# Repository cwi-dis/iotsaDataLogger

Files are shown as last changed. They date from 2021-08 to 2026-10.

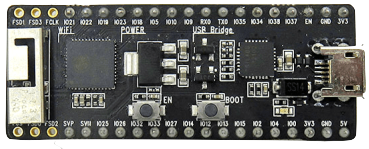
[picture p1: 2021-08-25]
extras/hardware/esp32-pico-kit-dev-board-v4-01.png

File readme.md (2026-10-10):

# iotsaDataLogger - web server to record time series from a sensor




IotsaDataLogger reads an analog sensor repeatedly at a configurable interval and records readings in a LittleFS-backed file on the device. Readings can be retrieved over the network as CSV data.

The device is intended to be battery-operated, taking readings at long intervals (minutes to hours) and using deep sleep between readings to conserve power. A DS1302 RTC module keeps wall-clock time across deep-sleep cycles and syncs from NTP whenever WiFi is available.

When the device wakes from sleep it takes a measurement and goes back to sleep, _unless the configured WiFi network is available_. When WiFi is available the device stays awake and can be read out.

The use case this was built for is monitoring a solar-powered holiday home: the device reads battery voltage once an hour, running on the solar battery itself. Whenever you visit and enable the WiFi network, you can retrieve weeks of readings.

Home page is <https://github.com/cwi-dis/iotsaDataLogger>.

## Power and WiFi behaviour

On power-up or reset the device:

1. Takes a measurement and stores it.
2. Checks whether the configured WiFi network is available.
3. If WiFi is **not** available: goes back into deep sleep until the next interval.
4. If WiFi **is** available: stays awake, connects, syncs time from NTP, and serves data over HTTP until powered off or reset.

So to read out the device, simply make sure the WiFi network is up and **press the reset button** (or power-cycle the device). It will reboot, find the network, and stay awake.

The reset button on the reference hardware (see `extras/hardware/`) is wired to the ESP32 EN pin. There is no separate "stay awake" button — WiFi availability is the only criterion.

To reconfigure the device (change WiFi network, hostname, etc.), follow the standard [iotsa configuration procedure](https://github.com/cwi-dis/iotsa): visit `http://yourdevice.local/config`, request configuration mode, then power-cycle within a few minutes.

## Hardware requirements

- An ESP32-based board (tested: `esp32thing`, `pico32`).
- An analog sensor connected to GPIO 34.
- A DS1302 RTC module (optional but recommended for accurate timestamps).

## Software requirements

- PlatformIO (recommended) or Arduino IDE.
- The [iotsa framework](https://github.com/cwi-dis/iotsa).

## Building and configuring

Build using PlatformIO and flash to the board. Then configure the device — see the [iotsa](https://github.com/cwi-dis/iotsa) instructions for general guidance:

- WiFi network and hostname
- Timezone and NTP server

Configure the acquisition module:

- Interval between readings
- Whether to use deep sleep
- ADC calibration: `adcMultiply` (scale factor) and `adcOffset` (offset). The ESP32 ADC is not very linear, and there is also the voltage divider to account for. In practice, if your voltage range is bounded (e.g. 10–16V for a lead-acid battery), leaving `adcOffset` at 0 and only tuning `adcMultiply` against a known reference voltage is sufficient.

### Annotations

The `annotations` module (`/annotations`, `/api/annotations`) stores free-form key/value strings, a bit like DNS TXT records. The device does not use them itself; they tell tools what the data is and how to present it. The Python tool understands these keys:

- `description`: human-readable description, used in graph titles.
- `location`: `LATITUDE,LONGITUDE`, for the sunshine overlay. `location.name`: place name (looked up if `location` isn't set).
- `v.label`, `v.unit`: what the measured value is (default `Voltage`, `V`). `v` is the channel name; there is only one channel for now.
- `v.threshold`, `v.threshold.label`: a horizontal line in the graphs, e.g. a battery's shutdown-risk voltage. More as `v.threshold.2`, `v.threshold.2.label`, and so on.

The module is generic, and may move into iotsa itself.

## Python tool

The `extras/python/` directory contains the `iotsaDataLogger` Python package and tool for retrieving, storing, merging, and graphing data. The package layers are usable on their own: `DataLoggerDevice` (device access through `iotsa`), `DataStore` (local files), and the `plot` functions (which return a matplotlib figure).

### Setup

(If instructions in this repo's parent directory cover venv setup, those take precedence over the steps below.)

From the repo root:

```sh
python3 -m venv .venv
source .venv/bin/activate
pip install -e ../iotsa/extras/python/
pip install -e extras/python/
```

Or, if you have the `requirements_dev.txt`:

```sh
python3 -m venv .venv
source .venv/bin/activate
pip install -r extras/python/requirements_dev.txt
pip install -e extras/python/
```

### Usage

The tool has sub-commands. Devices are named by their iotsa name (`accugroot` or `accugroot.local`), and local data for a device is kept in the data directory (`--datadir`, default the current directory) as:

- `DEVICE.csv`: long-term daily min/max history (same format as the device's `/datalogger/data_daily.csv`).
- `DEVICE-detail.csv`: raw readings from the most recent pull, overwritten every time.
- `DEVICE.json`: the device's annotations (see above). `pull` refreshes it from the device; for firmware without the annotations module it can be written by hand.

Fetch the device's raw data (stored as `DEVICE-detail.csv`), and merge the device's daily summaries into the long-term history (older firmware without daily summaries: computed from the raw data):

```sh
iotsaDataLogger pull yourdevice
```

Graph the long-term daily history, with a sunshine overlay if a location is configured:

```sh
iotsaDataLogger plot yourdevice
iotsaDataLogger plot yourdevice --sunlight Amsterdam --save history.png
```

Graph the raw readings from the most recent pull:

```sh
iotsaDataLogger recent yourdevice --days 7
```

Print the device's daily summaries (or raw readings with `--raw`) as CSV, without storing anything:

```sh
iotsaDataLogger dump yourdevice
```

Show or change the device's annotations (this also refreshes `DEVICE.json`). An empty value removes a key. After reflashing a device, `--from-local` uploads `DEVICE.json` to it:

```sh
iotsaDataLogger annotate yourdevice
iotsaDataLogger annotate yourdevice description="small battery" v.threshold=11.5
iotsaDataLogger annotate yourdevice --from-local
```

Sub-commands that talk to the device accept the same connection options as the `iotsa` tool: `--protocol`, `--port`, `--noverify`, `--bearer`, `--credentials`. Use `iotsaDataLogger COMMAND --help` for details.

## Sample data

A sample CSV file is in `extras/sandbox/`. The accuklein/accugroot battery-voltage history (the real-world use case this tool was built for) lives in `lissabon-config/battery-health/` (private), reconstructed into daily min/max form.

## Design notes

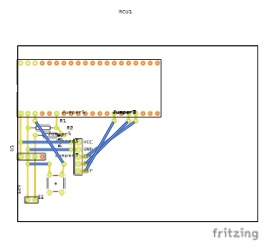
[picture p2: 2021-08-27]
extras/hardware/dataLogger_pcb.jpg

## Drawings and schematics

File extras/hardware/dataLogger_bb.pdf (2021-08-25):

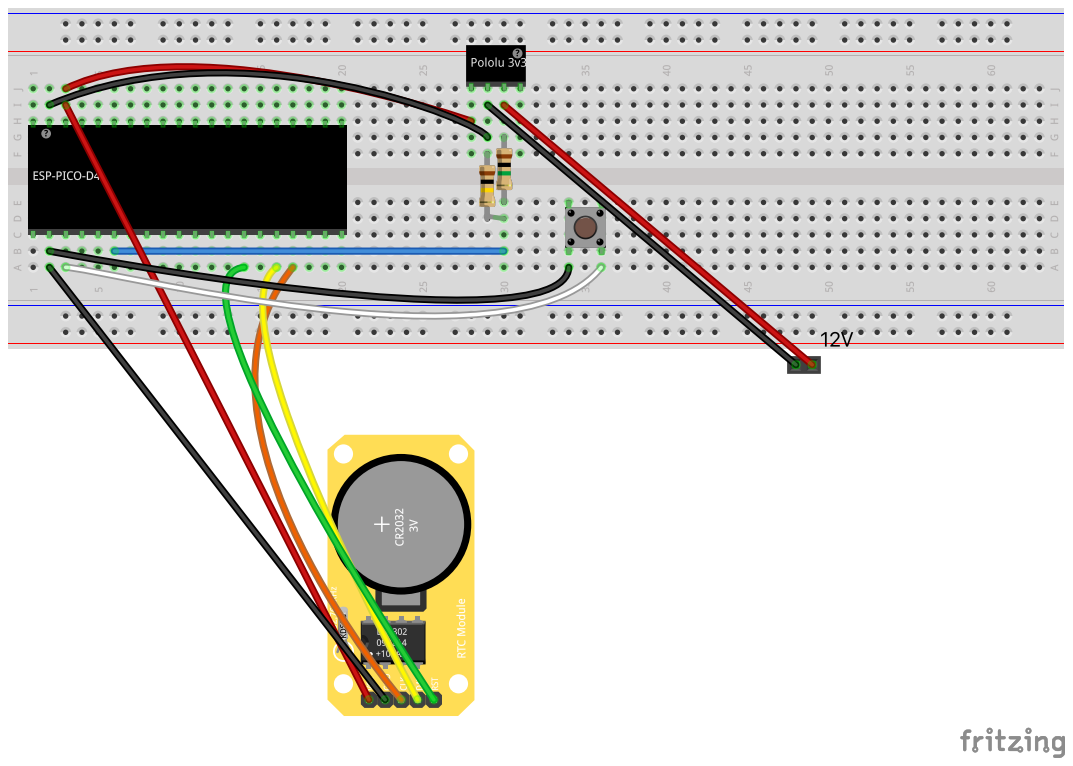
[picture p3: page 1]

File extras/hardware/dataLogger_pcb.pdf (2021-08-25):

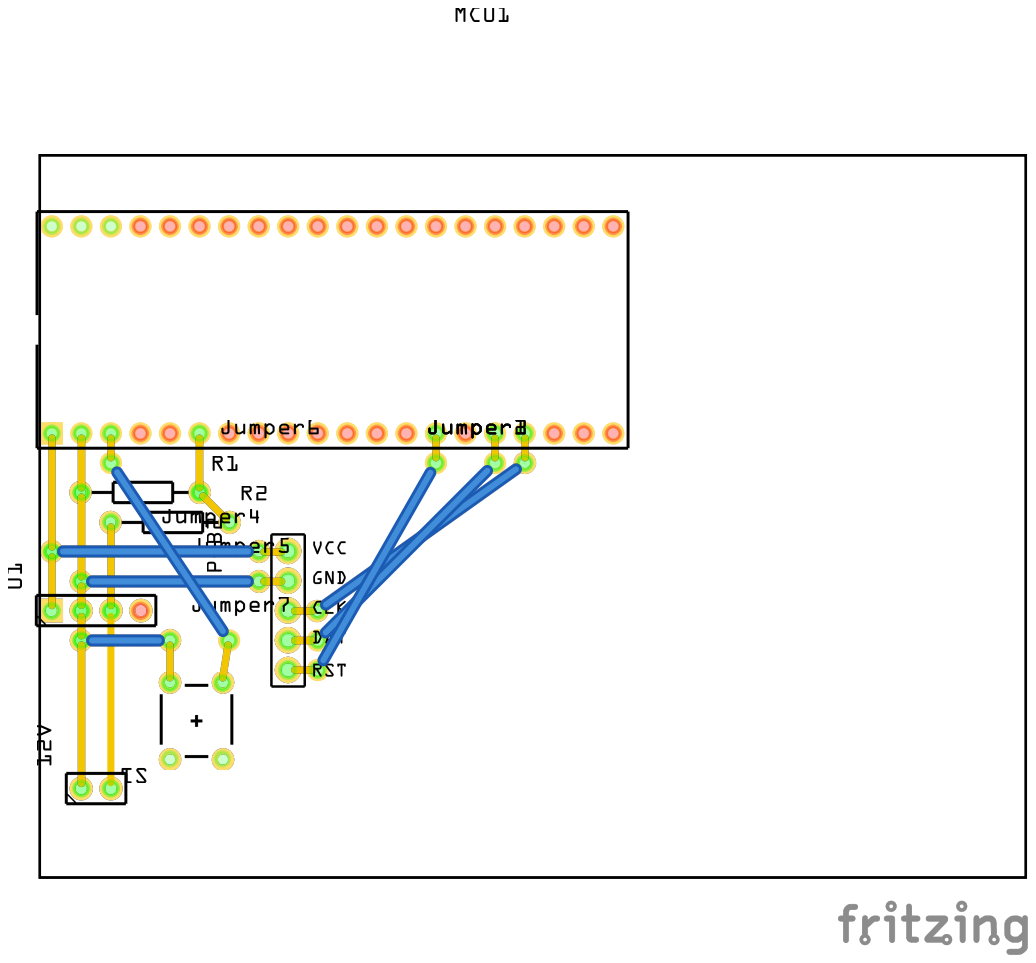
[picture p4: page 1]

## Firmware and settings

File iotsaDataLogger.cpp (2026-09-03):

#include "iotsaDataLogger.h"
#include "iotsaConfigFile.h"
#include <LittleFS.h>

#ifdef IOTSA_WITH_WEB
void
IotsaDataLoggerMod::webHandler() {
  bool anyChanged = false;
  if( api.webService->server->hasArg("interval")) {
    if (needsAuthentication()) return;
    String sInterval = api.webService->server->arg("interval");
    interval = sInterval.toInt();
    anyChanged = true;
  }
  if( api.webService->server->hasArg("adcMultiply")) {
    if (needsAuthentication()) return;
    String sv = api.webService->server->arg("adcMultiply");
    adcMultiply = sv.toFloat();
    anyChanged = true;
  }
  if( api.webService->server->hasArg("adcOffset")) {
    if (needsAuthentication()) return;
    String sv = api.webService->server->arg("adcOffset");
    adcOffset = sv.toFloat();
    anyChanged = true;
  }
  if( api.webService->server->hasArg("deepSleep")) {
    if (needsAuthentication()) return;
    String sv = api.webService->server->arg("deepSleep");
    deepSleep = (bool)sv.toInt();
    anyChanged = true;
  }
  if( api.webService->server->hasArg("rawRetentionDays")) {
    if (needsAuthentication()) return;
    String sv = api.webService->server->arg("rawRetentionDays");
    rawRetentionDays = sv.toInt();
    anyChanged = true;
  }
  if (anyChanged) configSave();

  String message = "<html><head><title>Timed Data Logger Module</title></head><body><h1>Timed Data Logger Module</h1>";

  message += "<h2>Acquisition settings</h2>";
  message += "<form method='get'>Interval (seconds): <input name='interval' value='";
  message += String(interval);
  message += "'><br>ADC multiplication factor: <input name='adcMultiply' value='";
  message += String(adcMultiply, 5);
  message += "'><br>ADC offset: <input name='adcOffset' value='";
  message += String(adcOffset, 5);
  message +="'><br><input type='checkbox' name='deepSleep' value='1'";
  if (deepSleep) message += " checked";
  message += ">Deep Sleep between acquisitions (unless WiFi is available)";
  message += "<br>Raw data retention (days): <input name='rawRetentionDays' value='";
  message += String(rawRetentionDays);
  message += "'>";
  message += "<br><input type='submit'></form>";

  size_t fsTotal = LittleFS.totalBytes();
  size_t fsUsed = LittleFS.usedBytes();
  int fsPct = (int)(100.0f * fsUsed / fsTotal);
  char fsBuf[64];
  snprintf(fsBuf, sizeof(fsBuf), "%d KB / %d KB (%d%%)", (int)(fsUsed/1024), (int)(fsTotal/1024), fsPct);
  message += "<h2>Storage</h2><p>Flash filesystem: ";
  message += fsBuf;
  message += "</p>";

  message += "<h2>Daily measurements</h2>";
  store->toHTMLDaily(message);
  message += "<h2>Recent raw measurements</h2>";
  store->toHTML(message);
  message += "</body></html>";
  api.webService->server->send(200, "text/html", message);
}

String IotsaDataLoggerMod::info() {
  String message = "<p>Timed data logger. See <a href=\"/datalogger\">/datalogger</a> for configuration.</p>"
    "<p><a href=\"/datalogger/data_daily.csv\">/datalogger/data_daily.csv</a> &mdash; daily min/max summaries (older data compressed, one row per day).</p>"
    "<p><a href=\"/datalogger/data.csv\">/datalogger/data.csv</a> &mdash; recent measurements at full resolution.</p>";
  return message;
}
#endif // IOTSA_WITH_WEB

bool IotsaDataLoggerMod::getHandler(const char *path, JsonObject& reply) {
  store->toJSON(reply, true);
  reply["interval"] = interval;
  reply["adcMultiply"] = adcMultiply;
  reply["adcOffset"] = adcOffset;
  reply["deepSleep"] = deepSleep;
  reply["rawRetentionDays"] = rawRetentionDays;
  reply["fsUsed"] = (int)LittleFS.usedBytes();
  reply["fsTotal"] = (int)LittleFS.totalBytes();
  return true;
}

void
IotsaDataLoggerMod::dataHandler() {
  store->toCSV(app.server);
}

void
IotsaDataLoggerMod::dailyHandler() {
  store->toCSVDaily(app.server);
}

bool IotsaDataLoggerMod::putHandler(const char *path, const JsonVariant& request, JsonObject& reply) {
  if (!request.is<JsonObject>()) return false;
  JsonObject reqObj = request.as<JsonObject>();
  bool anyChanged = false;
  bool anySet = false;
  if (getFromRequest<int>(reqObj, "interval", interval)) {
    anyChanged = true;
  }
  if (getFromRequest<float>(reqObj, "adcMultiply", adcMultiply)) {
    anyChanged = true;
  }
  if (getFromRequest<float>(reqObj, "adcOffset", adcOffset)) {
    anyChanged = true;
  }
  if (getFromRequest<bool>(reqObj, "deepSleep", deepSleep)) {
    anyChanged = true;
  }
  if (getFromRequest<int>(reqObj, "rawRetentionDays", rawRetentionDays)) {
    anyChanged = true;
  }
  timestamp_type ts;
  if (getFromRequest<timestamp_type>(reqObj, "forgetBefore", ts)) {
    store->forget(ts);
    anySet = true;
  }
  if (anyChanged) {
    configSave();
  }
  return anyChanged||anySet;
}

void IotsaDataLoggerMod::setup() {
  configLoad();
  //
  // The esp32 ADC seems to have pretty bad linearity.
  // Attempting to fix based on https://www.esp32.com/viewtopic.php?t=2881
  // and https://docs.espressif.com/projects/esp-idf/en/latest/esp32/api-reference/peripherals/adc.html
  //
  analogSetWidth(10);
  analogSetPinAttenuation(PIN_ANALOG_IN, ADC_6db);
}

void IotsaDataLoggerMod::lateSetup() {
  name = "datalogger";
#ifdef IOTSA_WITH_WEB
  // /datalogger (the module's own page) is registered by api.setup() below.
  // The two CSV endpoints are extra routes, registered directly on the server.
  app.server->on("/datalogger/data.csv", std::bind(&IotsaDataLoggerMod::dataHandler, this));
  app.server->on("/datalogger/data_daily.csv", std::bind(&IotsaDataLoggerMod::dailyHandler, this));
#endif
  api.setup("datalogger", true, true);
}

void IotsaDataLoggerMod::configLoad() {
  IotsaConfigFileLoad cf("/config/datalogger.cfg");
  cf.get("interval", interval, 10);
  cf.get("adcMultiply", adcMultiply, 1);
  cf.get("adcOffset", adcOffset, 0);
  cf.get("deepSleep", deepSleep, false);
  cf.get("rawRetentionDays", rawRetentionDays, 14);
}

void IotsaDataLoggerMod::configSave() {
  IotsaConfigFileSave cf("/config/datalogger.cfg");
  cf.put("interval", interval);
  cf.put("adcMultiply", adcMultiply);
  cf.put("adcOffset", adcOffset);
  cf.put("deepSleep", deepSleep);
  cf.put("rawRetentionDays", rawRetentionDays);
}
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

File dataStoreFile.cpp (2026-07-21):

#include "dataStoreFile.h"


const char* datastoreFilename = "/littlefs/datastore.dat";
const char* datastoreDailyFilename = "/littlefs/datastore_daily.dat";


void DataStoreFile::add(timestamp_type ts, const dataStoreItem& value)
{
  FILE *fp = fopen(datastoreFilename, "ab");
  if (fp == NULL) {
    IotsaSerial.println("DataStoreFile: add: fopen failed");
    return;
  }
  DataStoreFileRecord rec;
  rec.value = value;
  rec.timestamp = ts;
  size_t sz = fwrite(&rec, sizeof(rec), 1, fp);
  if (sz != 1) {
    IotsaSerial.println("DataStoreFile: add: fwrite failed");
  }
  fclose(fp);
  latestTimestamp = ts;
  if (nItem >= 0) nItem++;
}

timestamp_type DataStoreFile::latest() {
  if (latestTimestamp != 0) return latestTimestamp;
  FILE *fp = fopen(datastoreFilename, "rb");
  if (fp == NULL) {
    IotsaSerial.println("DataStoreFile: latest: fopen failed");
    return 0;
  }
  DataStoreFileRecord rec;
  rec.timestamp = 0;
  int sts = fseek(fp, -sizeof(rec), SEEK_END);
  if (sts != 0) {
    IotsaSerial.println("DataStoreFile: latest: fseek failed");
  }
  long pos = ftell(fp);
  nItem = (pos / sizeof(rec))+1;
  size_t sz = fread(&rec, sizeof(rec), 1, fp);
  if (sz != 1) {
    IotsaSerial.println("DataStoreFile: latest: fread failed");
  }
  fclose(fp);
  return rec.timestamp;
}

int DataStoreFile::size() {
  if (nItem <= 0) {
    // Getting most recent timestamp also initializes nItem
    (void)latest();
  }
  return nItem;
}

void DataStoreFile::forget(timestamp_type ts) {
  const char* backup = "/littlefs/datastore.001";
  (void)remove(backup);
  int sts = rename(datastoreFilename, backup);
  if (sts != 0) {
    IotsaSerial.println("DataStoreFile: forget: cannot rename datastore file");
    return;
  }
  FILE *ifp = fopen(backup, "rb");
  FILE *ofp = fopen(datastoreFilename, "wb");
  if (ifp == NULL || ofp == NULL) {
    IotsaSerial.println("DataStoreFile: forget: cannot open files");
    return;
  }
  while(true) {
    DataStoreFileRecord rec;
    size_t sz = fread(&rec, sizeof(rec), 1, ifp);
    if (sz != 1) break;
    if (rec.timestamp >= ts) {
      (void)fwrite(&rec, sizeof(rec), 1, ofp);
    }
  }
  latestTimestamp = 0;
  nItem = -1;
  fclose(ifp);
  fclose(ofp);
}

void DataStoreFile::compress(timestamp_type now, int rawRetentionDays) {
  FILE *fp = fopen(datastoreFilename, "rb");
  if (fp == NULL) return;
  DataStoreFileRecord first;
  size_t sz = fread(&first, sizeof(first), 1, fp);
  fclose(fp);
  if (sz != 1) return;

  timestamp_type cutoff = now - (timestamp_type)rawRetentionDays * 24 * 3600;
  int cutoff_day = (int)(cutoff / 86400);
  if ((int)(first.timestamp / 86400) >= cutoff_day) return;

  const char* backup = "/littlefs/datastore.001";
  (void)remove(backup);
  if (rename(datastoreFilename, backup) != 0) {
    IotsaSerial.println("DataStoreFile: compress: cannot rename");
    return;
  }
  FILE *ifp = fopen(backup, "rb");
  FILE *ofp = fopen(datastoreFilename, "wb");
  FILE *dfp = fopen(datastoreDailyFilename, "ab");
  if (ifp == NULL || ofp == NULL || dfp == NULL) {
    IotsaSerial.println("DataStoreFile: compress: cannot open files");
    if (ifp) fclose(ifp);
    if (ofp) fclose(ofp);
    if (dfp) fclose(dfp);
    return;
  }

  int current_day = -1;
  DataStoreDailyFileRecord drec;

  while (true) {
    DataStoreFileRecord rec;
    if (fread(&rec, sizeof(rec), 1, ifp) != 1) break;
    int day = (int)(rec.timestamp / 86400);
    if (day < cutoff_day) {
      if (day != current_day) {
        if (current_day >= 0) fwrite(&drec, sizeof(drec), 1, dfp);
        current_day = day;
        drec.min_t = rec.timestamp;
        drec.max_t = rec.timestamp;
        drec.min_v = rec.value;
        drec.max_v = rec.value;
        drec.n = 1;
      } else {
        if (rec.value < drec.min_v) { drec.min_v = rec.value; drec.min_t = rec.timestamp; }
        if (rec.value > drec.max_v) { drec.max_v = rec.value; drec.max_t = rec.timestamp; }
        drec.n++;
      }
    } else {
      fwrite(&rec, sizeof(rec), 1, ofp);
    }
  }
  if (current_day >= 0) fwrite(&drec, sizeof(drec), 1, dfp);

  fclose(ifp);
  fclose(ofp);
  fclose(dfp);
  (void)remove(backup);
  latestTimestamp = 0;
  nItem = -1;
  IotsaSerial.println("DataStoreFile: compress: done");
}

void DataStoreFile::toCSVDaily(IotsaWebServer *server) {
  server->setContentLength(CONTENT_LENGTH_UNKNOWN);
  server->send(200, "text/csv", "");
  server->sendContent("date,min_t,max_t,min_v,max_v,n\r\n");

  // Stream completed daily records
  FILE *fp = fopen(datastoreDailyFilename, "rb");
  if (fp != NULL) {
    while (true) {
      DataStoreDailyFileRecord rec;
      if (fread(&rec, sizeof(rec), 1, fp) != 1) break;
      _sendDailyCSV(rec, server);
    }
    fclose(fp);
  }

  // On-the-fly aggregation of remaining raw records
  fp = fopen(datastoreFilename, "rb");
  if (fp == NULL) return;

  int current_day = -1;
  DataStoreDailyFileRecord drec;

  while (true) {
    DataStoreFileRecord rec;
    if (fread(&rec, sizeof(rec), 1, fp) != 1) break;
    int day = (int)(rec.timestamp / 86400);
    if (day != current_day) {
      if (current_day >= 0) _sendDailyCSV(drec, server);
      current_day = day;
      drec.min_t = rec.timestamp;
      drec.max_t = rec.timestamp;
      drec.min_v = rec.value;
      drec.max_v = rec.value;
      drec.n = 1;
    } else {
      if (rec.value < drec.min_v) { drec.min_v = rec.value; drec.min_t = rec.timestamp; }
      if (rec.value > drec.max_v) { drec.max_v = rec.value; drec.max_t = rec.timestamp; }
      drec.n++;
    }
  }
  if (current_day >= 0) _sendDailyCSV(drec, server);
  fclose(fp);
}

void DataStoreFile::_sendDailyCSV(DataStoreDailyFileRecord rec, IotsaWebServer* server) {
  char buf[200];
  std::string date = FORMAT_DATE(rec.min_t);
  std::string min_ts = FORMAT_TIMESTAMP(rec.min_t);
  std::string max_ts = FORMAT_TIMESTAMP(rec.max_t);
  snprintf(buf, sizeof(buf), "\"%s\",\"%s\",\"%s\",%f,%f,%d\r\n",
    date.c_str(),
    min_ts.c_str(),
    max_ts.c_str(),
    (float)rec.min_v,
    (float)rec.max_v,
    (int)rec.n
  );
  server->sendContent(String(buf));
}
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

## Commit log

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2021-08-22 The esp32 ADC is pretty non-linear. Add parameters to fix this.
    [iotsaDataLogger.cpp]
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2021-08-25 Added hardware layout files
    [dataLogger.fzz]
2021-08-27 Minor tweaks
    [dataLogger.fzz]
2021-09-26 Added some sample data files
    [accugroot.csv, accuklein.csv]
2022-08-20 Handle sleep different, so we also sleep when we have not yet taken a measurement
    [accuklein.csv]
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2022-09-25 Added requirements, new measurements
    [accugroot.csv, accuklein.csv]
2023-07-30 More sample data files
    [accugroot-jul23.csv, accuklein-jul23.csv, unknown-jun23.csv]
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2025-04-27 More sample files. To be sorted at some point
    [accugroot-april24.csv, accugroot-jul24.csv, accugroot-maart25.csv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]
2026-06-05 More samples.
    [accugroot-aug25.csv, accugroot-jan26.csv, accugroot-mar26.csv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]
2026-06-06 More readings from today, while debugging battery shutdown problem
    [accuklein-2026-06-06.csv]
2026-06-06 Switch data retrieval from REST JSON to CSV endpoint
    Fetch /datalogger/data.csv or /datalogger/archive.csv directly instead
    of the /api/datalogger REST endpoint, which no longer returns measurement
    data. Reuse the IotsaDevice protocol handler for protocol detection and
    auth; make the raw request via requests.get(). Drop the --bufsize option
    which was a workaround for the JSON buffer limit on the device.
2026-06-13 Fix CSV reading and add stdout fallback output
    QUOTE_NONNUMERIC on DictReader caused header row fields to be converted
    to float, crashing on the 't' column name. Remove it from both read
    paths. Also print CSV to stdout when neither -o nor -g is given, rather
    than silently discarding the data.
2026-06-13 Update README to reflect current state of the project
    Fix wrong home page URL (pointed to iotsaSensor), update hardware from
    ESP8266 to ESP32, replace JSON API references with CSV, remove obsolete
    --bufsize mention, replace outdated venv setup with current instructions,
    and add concrete usage examples for the Python tool.
2026-06-13 Document power/WiFi behaviour and clarify ADC calibration
    Add section explaining the deep-sleep/WiFi wake cycle and how to get
    the device on the network (press reset while WiFi is available).
    Clarify that adcOffset=0 is intentional for bounded voltage ranges —
    only adcMultiply needs tuning.
2026-06-13 Add June 2026 data snapshots for accuklein and accugroot
    [accugroot-2026-06-13.csv, accuklein-2026-06-13.csv]
2026-06-13 Implement tiered storage: raw 14-day window + daily summaries
    - DataStoreFile.compress(): on each wake, moves raw records older than
    14 days into datastore_daily.dat as per-day min/max/n aggregates
    - DataStoreFile.toCSVDaily(): serves data_daily.csv by streaming
    datastore_daily.dat then aggregating remaining raw records on the fly
    - /datalogger/data_daily.csv endpoint replaces /datalogger/archive.csv
    - Removed archive() / should_archive() from DataStore interface
    - Python tool: daily data is now the default (--raw for per-reading data)
    - Removed xxxjack debug printfs from loop()
    [dataStoreFile.cpp, iotsaDataLogger.cpp]
2026-06-14 Pin pico32 partition table to preserve LittleFS size
    espressif32 platform 6.9.0 added a coredump partition by default,
    shrinking LittleFS from 1472KB (368 blocks) to 1408KB (352 blocks).
    Any device with existing LittleFS data formatted at 368 blocks would
    crash on mount with: assert failed: lfs_fs_grow_ (block_count >= lfs->block_count)
    Add a custom partitions.csv matching the original layout (no coredump)
    and wire it up in platformio.ini.
    [partitions.csv]
2026-06-19 Improve datalogger web UI and make raw retention configurable
    - Homepage now links to daily and raw CSV endpoints instead of /api/datalogger
    - Datalogger page shows daily summary (count, first/last) before raw data
    - rawRetentionDays is now a configurable field (default 14), exposed via web form, REST, and config file
    - Drop summary parameter from toHTML; add toHTMLDaily for daily store status
    - Remove Refresh button and duplicate CSV links from datalogger page
2026-06-19 Improve graph output and add --sunlight overlay option
    - graph() now uses fill_between for daily min/max, proper date tick formatting,
    and a title derived from the device hostname
    - --sunlight LOCATION geocodes the location via Open-Meteo and adds a second
    subplot with sunshine hours and solar radiation for the same date range;
    --sunlight alone implies --graph
2026-06-19 Fix graph title to use device hostname
2026-07-11 Add accuklein data snapshot through battery replacement
    Merged raw device data (through 2026-07-11) with the prior local
    snapshot. Confirms the recurring overnight shutdown-risk dips
    (down to 10.97V on 07-06) persisted right up until the battery was
    physically replaced on 07-11.
    [accuklein-2026-07-11.csv]
2026-07-11 Retire raw accuklein/accugroot sample CSVs, moved to lissabon-config
    The battery-voltage history this tool was built to collect now lives
    in lissabon-config/battery-health/ as reconstructed daily min/max
    CSVs (canonical form going forward, appended to periodically from the
    devices). The raw per-reading CSVs here are fully superseded and
    recoverable from git history if raw precision is ever needed again.
    Updated the README's sample-data pointer accordingly.
    [accugroot-2026-06-13.csv, accugroot-april24.csv, accugroot-aug25.csv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]
2026-07-21 Enable WITH_FILESBACKUP so the actual logged data can be backed up
    The datalogger's readings live in raw LittleFS files (datastore.dat,
    datastore_daily.dat), entirely outside the config-file system --
    IotsaDataLoggerMod's REST getHandler only exposes a summary, so the
    standard per-module JSON backup never captured the actual data. This is
    the one app in the iotsa-group where that data is exactly what a backup
    should cover, and IotsaFilesBackupMod was already scaffolded in, just
    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
2026-07-21 Migrate remaining ArduinoJson v6 API calls to v7
    createNestedArray("data") -> ["data"].to<JsonArray>(),
    createNestedObject() -> add<JsonObject>(), in both DataStoreFile and
    DataStoreMemory. Deprecated but still functional pre-fix, so no build
    break, just latent warnings.
    [dataStoreFile.cpp]
2026-07-21 Replace deprecated JsonObject::containsKey with getFromRequest<T>
    containsKey() is deprecated in ArduinoJson v7 (use obj[key].is<T>()
    instead). Switched putHandler to the same getFromRequest<JT,CT> helper
    already used throughout the rest of the iotsa/lissabon codebase, which
    wraps exactly that check. Also puts deepSleep's bool handling on the
    documented-safe getFromRequest<bool> path (cwi-dis/iotsa#118) instead of
    a raw JsonVariant-to-bool assignment.
    [iotsaDataLogger.cpp]
2026-08-12 Use cmArduinoJWT fork instead of unmaintained ArduinoJWT
    Fixes cwi-dis/iotsa#184
2026-08-13 Replace fork --git-url installs with Library Manager references in Arduino CI
    cmArduinoJWT and esp32_idf5_https_server_compat are now published in the
    Arduino Library Manager, so the arduino-cli workflow no longer needs
    --git-url installs for them (esp32_idf5_https_server resolves
    transitively via esp32_idf5_https_server_compat's own depends=). iotsa
    itself is still installed via --git-url, pinned to the branch/ref under
    test.
    cwi-dis/iotsa#96
2026-08-13 arduino-cli: force a fresh library index before name-based lib installs
    The previous commit switched cmArduinoJWT and esp32_idf5_https_server_compat
    from --git-url installs to name-based Library Manager lookups. That exposed
    a latent bug in the "Cache Arduino CLI" step: its cache key hashes
    *_index.json in the repo working directory, which doesn't exist here, so
    the key is effectively static and a cache-hit silently restores whatever
    library_index.json was saved on the very first run -- forever, since
    arduino-cli only auto-downloads that index when it's completely absent,
    never when it's merely stale.
    Confirmed locally (with arduino-cli installed via brew): installing
    cmArduinoJWT against a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
2026-08-14 ci: bump GitHub Actions to current majors (checkout@v7, setup-python@v7, upload-artifact@v7, cache@v6)
    These were pinned to versions from 2020-2021 (checkout@v2, setup-python@v2 -
    both Node16, upload-artifact@v4, cache@v2), well past their supported
    window. Matches the versions already verified working in iotsa itself.
2026-08-29 Migrate to iotsa v3 API + vendor board definitions (cwi-dis/iotsa#199)
    - IotsaApiMod -> IotsaModule; serverSetup() -> lateSetup(); handler() ->
    webHandler() reaching the server via api.webService->server; drop manual
    server->on() for the module's own page; bare api.setup("datalogger");
    /datalogger/data.csv + data_daily.csv moved to app.server->on(); application
    .serverSetup() -> application.lateSetup(). IOTSA_WITH_WEB guards kept (repo's
    own style). DataStore classes already take IotsaWebServer* by parameter.
    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
    [partitions.csv]
2026-08-29 Move app glue from the .ino into mainDataLogger.cpp
    Follows the current file-structure convention (examples/Skeleton, iotsaNeoClock):
    the .ino is now a bare #include <iotsa.h> to satisfy the Arduino builder, and
    the IotsaApplication/module instantiation + setup()/loop() live in
    mainDataLogger.cpp. Also dropped the stale "running on ESP8266" header comment.
    Claude-Session: https://claude.ai/code/session_01JK4ha63zeEirSaBRkjhC4p
2026-08-29 Flatten mainDataLogger.cpp: drop the WITH_* compile-time toggles
    The datalogger always builds the same module set, so the #define WITH_* /
    #ifdef scaffolding was pure ceremony. Instantiate wifi/ntp/rtc/ota/filesbackup/
    datalogger unconditionally; drop iotsaFiles + iotsaFilesUpload (were #undef'd,
    never built); drop the dead #ifndef ESP32 wdt guard (ESP32-only repo).
    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
2026-08-31 board-defs: re-vendor from iotsa v3.0a2
    Re-vendor iotsa-board-defs.ini verbatim from iotsa v3.0a2: [lolin32]
    now correctly resolves to board = lolin32_lite (cwi-dis/iotsa#228), plus the
    new [lolin32_oled] (cwi-dis/iotsa#229) and completed [crowpanel128] fields
    (cwi-dis/iotsa#226). This repo uses none of those sections; refresh only.
    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
2026-09-03 Sleep API rename: iotsaConfig -> iotsaController / iotsaStatus (cwi-dis/iotsa#106)
    iotsa#106 moved the sleep-inhibit API off IotsaConfig with no C++ forwarder,
    which broke the pico32 build on `iotsaConfig.canSleep()`. networkIsUp() still
    has a deprecated forwarder but moved too, so switch both:
    iotsaConfig.canSleep() -> iotsaController.canSleep()
    iotsaConfig.networkIsUp() -> iotsaStatus.networkIsUp()
    Builds clean (no deprecation warnings) against iotsa develop.
    Claude-Session: https://claude.ai/code/session_017NPviDGQHTQ9DxGH4ebYg8
    [iotsaDataLogger.cpp]
2026-10-05 Re-vendor iotsa board definitions; drop redundant min_spiffs.csv lines
    Refreshes iotsa-board-traits.ini / iotsa-board-defs.ini from iotsa
    develop (last vendored 2026-08-31). Picks up:
    - espressif32 platform pinned to 7.1.3 (cwi-dis/iotsa#269)
    - board_build.filesystem = littlefs, so `pio run -t uploadfs` builds an
    image the firmware can mount (cwi-dis/iotsa#269)
    - min_spiffs.csv as the default partition layout for all 4MB ESP32
    boards (cwi-dis/iotsa#245), making local board_build.partitions =
    min_spiffs.csv lines redundant -- removed where present
    - the NimBLE host-task stack flag for all ESP32 builds (cwi-dis/iotsa#127)
    Resolved config checked before/after with `pio project config`: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
2026-10-06 Adapt to iotsa's standard modules and per-application authenticator
    Re-vendor iotsa-board-traits.ini / iotsa-board-defs.ini from iotsa
    develop (status LED defines: IOTSA_PIN_LED, IOTSA_LED_NEOPIXEL,
    IOTSA_LED_ACTIVE_LOW).
    - Drop the IotsaWifiMod/IotsaOtaMod declarations: iotsa now creates the
    WiFi and OTA modules automatically (cwi-dis/iotsa#85).
2026-10-10 Python tool: sub-command CLI, absorb lissabon-config battery-health scripts (#11)
    Replace the flag-based CLI and DataLogger class with a layered package:
    records (CSV formats, daily aggregation/merge), device (fetch via iotsa),
    store (per-device DEVICE.csv / DEVICE-detail.csv / DEVICE.json), sunlight
    and plot (returning figures). The CLI has sub-commands pull, dump, plot
    and recent. Behaviour of pull/plot/recent matches the old battery-health
    scripts; output files are byte-identical.
2026-10-10 Python tool: pull merges the device's daily summaries instead of recomputing them
    pull now fetches /datalogger/data_daily.csv, which covers everything the
    device still holds (compressed days beyond the raw retention window plus
    on-the-fly summaries of raw days), and merges that into DEVICE.csv. Days
    are only computed from raw readings for firmware without that endpoint.
    The pull logic moved into the library (pull.pull()).
    Fixes #9
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2026-10-10 Python tool: presentation settings come from device annotations
    DEVICE.json now holds the device's annotations in flat key=value form
    (description, location, v.label, v.unit, v.threshold...), interpreted by
    annotations.py, which warns about keys it doesn't understand. pull caches
    the device's annotations there (but doesn't overwrite local ones with an
    empty set from a freshly flashed device). New annotate sub-command shows or
    changes them, and --from-local uploads DEVICE.json after reflashing.
2026-10-10 Python tool: don't ask for sunshine data from the future
    Device clocks running ahead (#14) put dates in the history that are later
    than today, and the open-meteo archive rejects those with HTTP 400. Clamp
    the date range to today, and tolerate null values for days not yet in the
    archive.
    Fixes #10
2026-10-10 Python tool: combine duplicate dates in daily summaries from the device
    The device's on-the-fly daily summaries group consecutive readings, so when
    its clock jumps back across midnight (as after accugroot's v3 upgrade fixed
    its clock, #14) the same date appears in two rows. Reading kept only the
    last one; now the rows are combined (min/max, n summed).
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
